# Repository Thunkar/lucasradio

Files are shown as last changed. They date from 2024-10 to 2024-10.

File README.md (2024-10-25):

# NFC based radio for kids

Uses a ESP32 A1S + PN532 NFC reader to mimic and old-school walkman

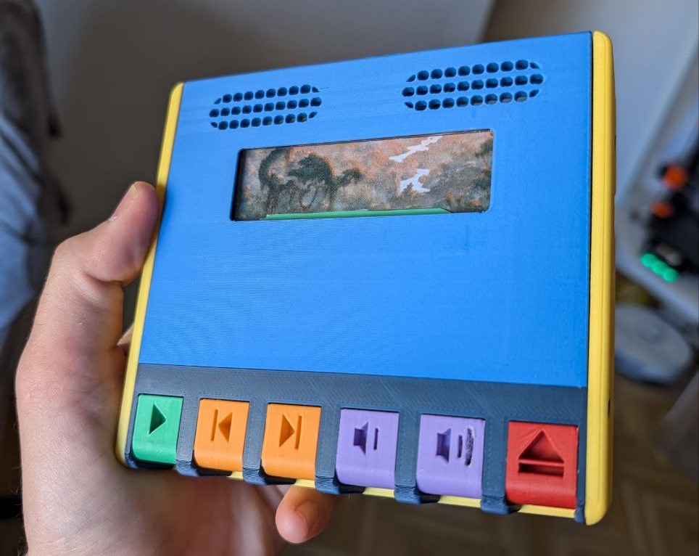
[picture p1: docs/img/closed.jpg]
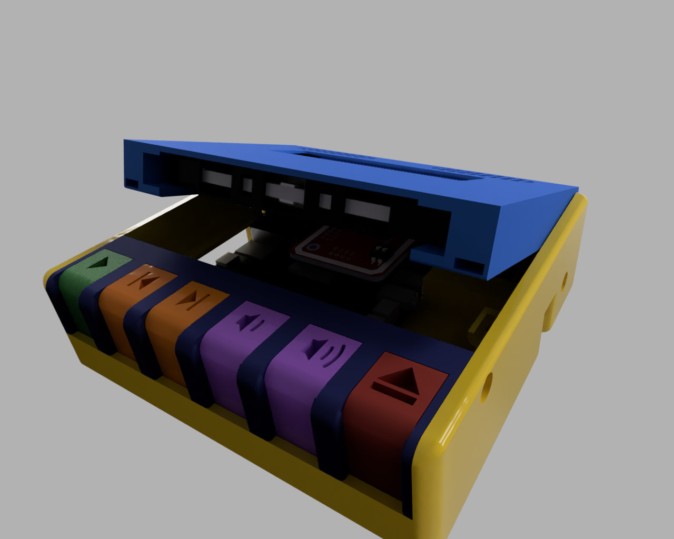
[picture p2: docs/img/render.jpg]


# Printing

PLA is fine, tolerances should allow for some wiggle room if your printer is not totally dialed in. Tested at 0.2mm layer height. Don't forget to follow on [printables](https://www.printables.com/model/1038471-nfc-walkman)!

# Ordering parts

You can check out the BOM [here](./docs/BOM.md)

# Assembly

Check out the guide [here](./docs/assembly.md)

# Flashing the code

The ESP32 A1S should be flashed with the `radio.ino` file. 

1. You will have to download and install the libraries at the top of the code, using the provided github links.
2. Use the ESP32 Dev Module board type
3. In compilation options, make sure to select "Huge app" partition scheme:

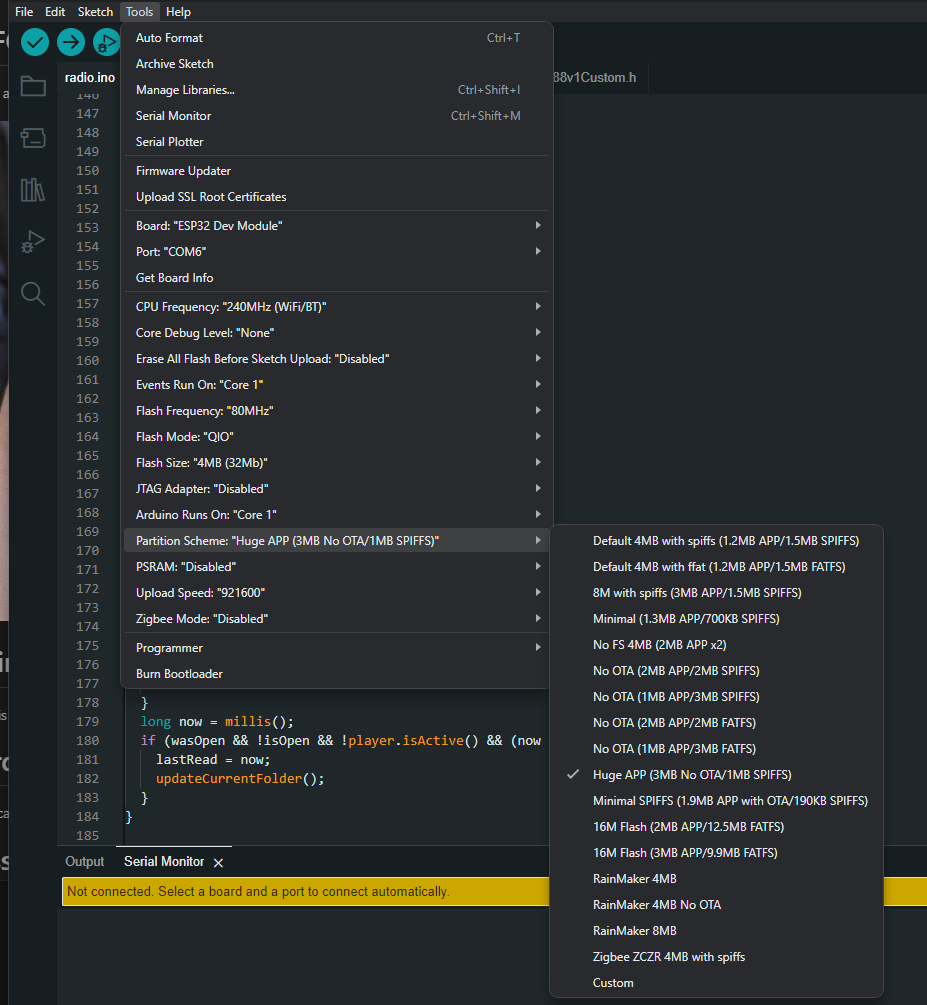
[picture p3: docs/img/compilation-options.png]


4. Click on upload!

# Operation

1. Get a microSD card and create a folder for each "cassette tape". Put some .mp3 files in each folder. Try to limit to ASCII characters!
2. Print some cassetes, and write an NFC tag for each, following the convention `P->foldername`. For example, if I have a folder in the SD card for "myalbum", the NFC tag should be written with a text record containing `P->myalbum`. (I used [Android NFC tools](https://play.google.com/store/apps/details?id=com.wakdev.wdnfc&hl=en) for this).
3. That's it! Turn on your walkman, insert your tape, and press play!

# Acknowledgements

* [Cassette model](https://www.printables.com/model/505572-cassette-tape) remixed from [Pete Farell](https://www.printables.com/@PeterFarell)'s design.

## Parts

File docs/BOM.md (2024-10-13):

# BOM

Links just provide a reference, other equivalents part might work (but the provided code expects these ones)
| Part | Link |
| ---- | ---- |
|ESP32 A1S ES8388 v2.2 | https://es.aliexpress.com/item/4000130915903.html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
|3W 4ohm speakers (x2) | https://es.aliexpress.com/item/1005006144805292.html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
|PN532 | https://es.aliexpress.com/item/1005007154965417.html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
|A3144 hall effect sensor | https://es.aliexpress.com/item/1005007816283535.html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
|M3 screws (6mm, 8mm, best to order the mix) | https://es.aliexpress.com/item/32794842281.html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
|M3 brass inserts (M3-OD 4.5, 3mm) | https://es.aliexpress.com/item/1005003582355741.html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
|4x2 magnet | https://es.aliexpress.com/item/1005003639279792.html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
|6x3 magnet | https://es.aliexpress.com/item/1005006291065081.html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
|20mm L x 5mm OD spring (x10) | https://es.aliexpress.com/item/1005005312536098.html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
|12mm latching Switch | https://es.aliexpress.com/item/1005004474876388.html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
|Battery (40mmx30mmx8mm max!) | https://es.aliexpress.com/item/1005006888230329.html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
|NFC tags | https://es.aliexpress.com/item/1005005872961523.html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

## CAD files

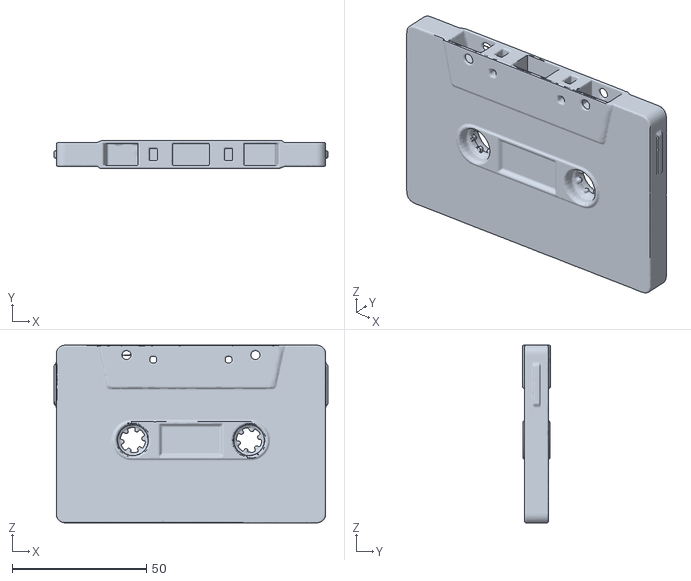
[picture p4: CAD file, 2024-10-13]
hw/cassette.stl
102.0 x 10.5 x 66.2

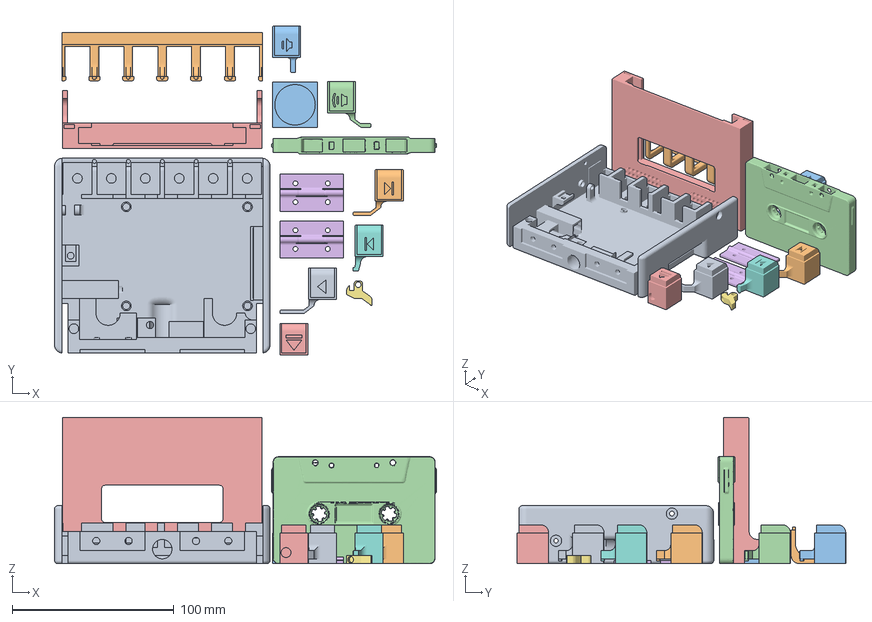
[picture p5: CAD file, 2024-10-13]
hw/recommended-orientation.3mf
236.4 x 203.4 x 90.5 mm
base.stl
buttonCover.stl
casette-tray.stl
cassette.stl
eject.stl
hinge.stl x 2
lock.stl
next.stl
play.stl
previous.stl
volumeDown.stl
volumeUp.stl
lid.stl

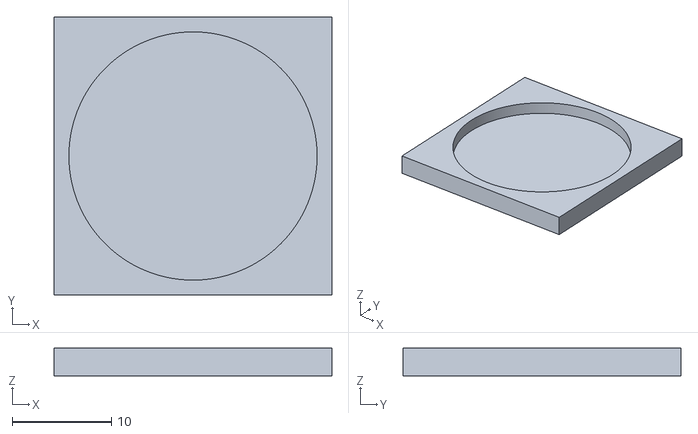
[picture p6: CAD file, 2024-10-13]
hw/casette-tray.stl
28.0 x 28.0 x 2.80

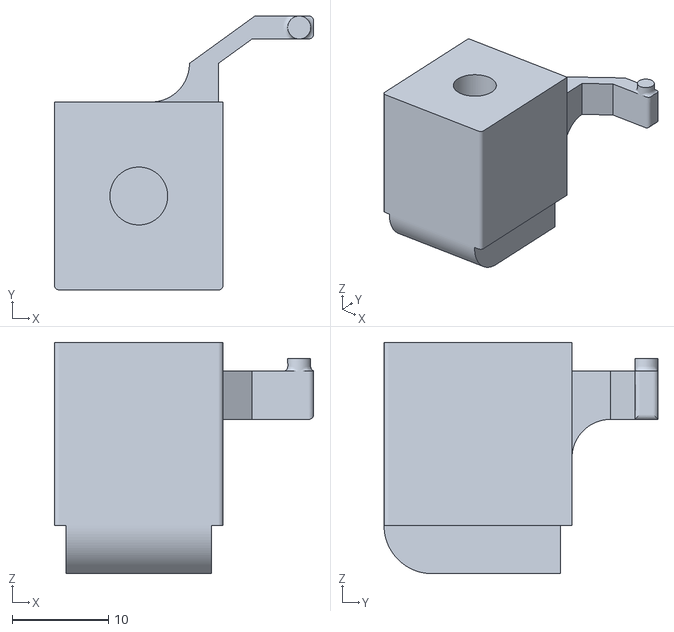
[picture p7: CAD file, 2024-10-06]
hw/volumeUp.stl
26.9 x 28.4 x 24.0

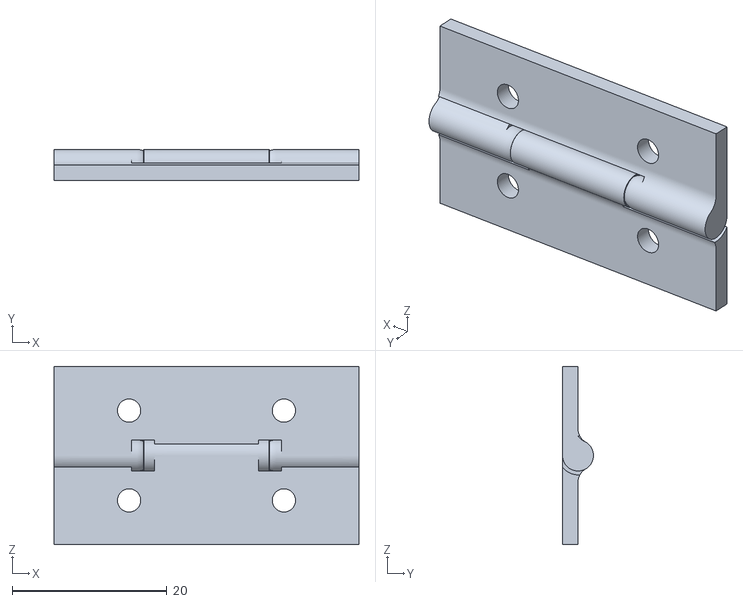
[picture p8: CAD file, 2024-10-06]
hw/hinge.stl
39.4 x 4.00 x 23.0

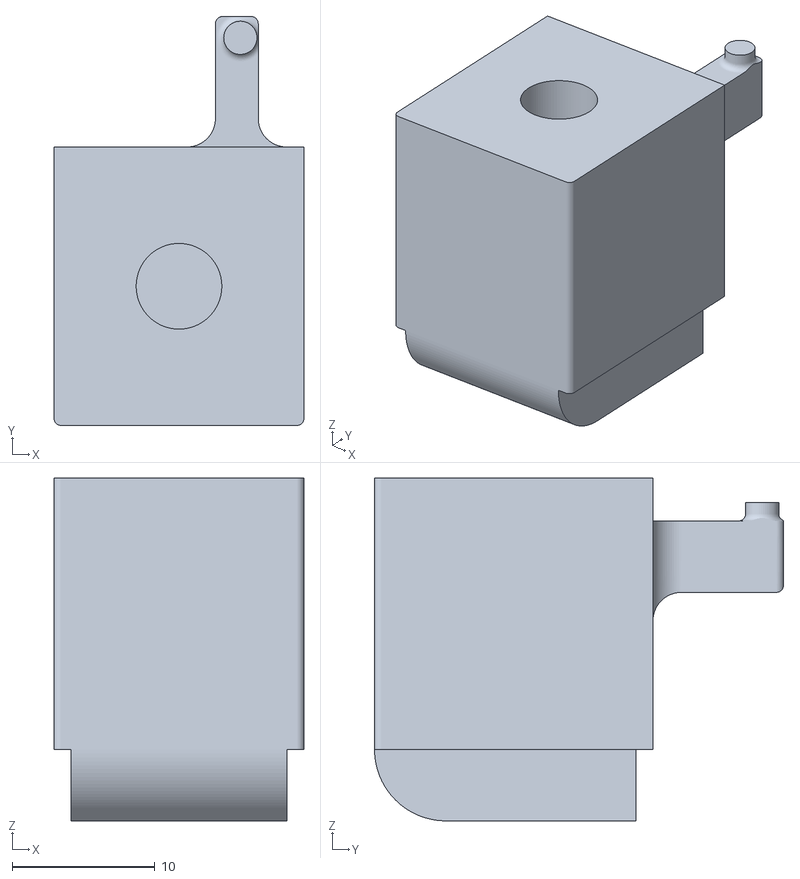
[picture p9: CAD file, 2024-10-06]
hw/volumeDown.stl
17.5 x 28.6 x 24.0

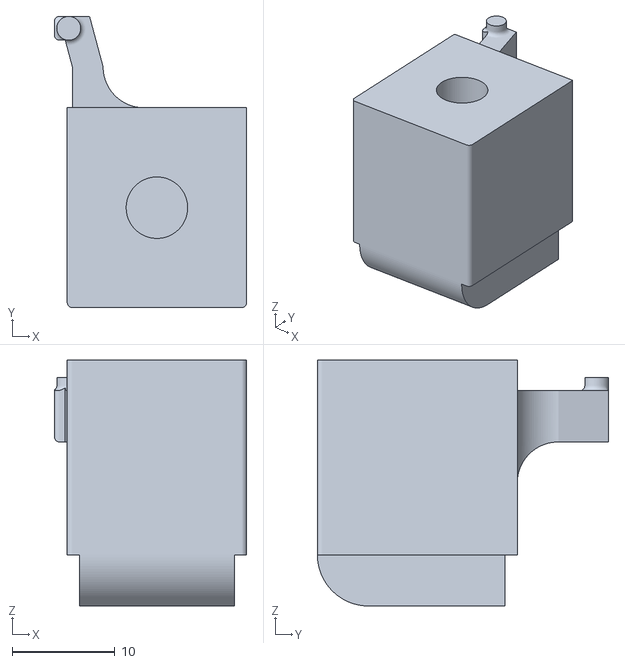
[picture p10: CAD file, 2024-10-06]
hw/next.stl
18.8 x 28.4 x 24.0

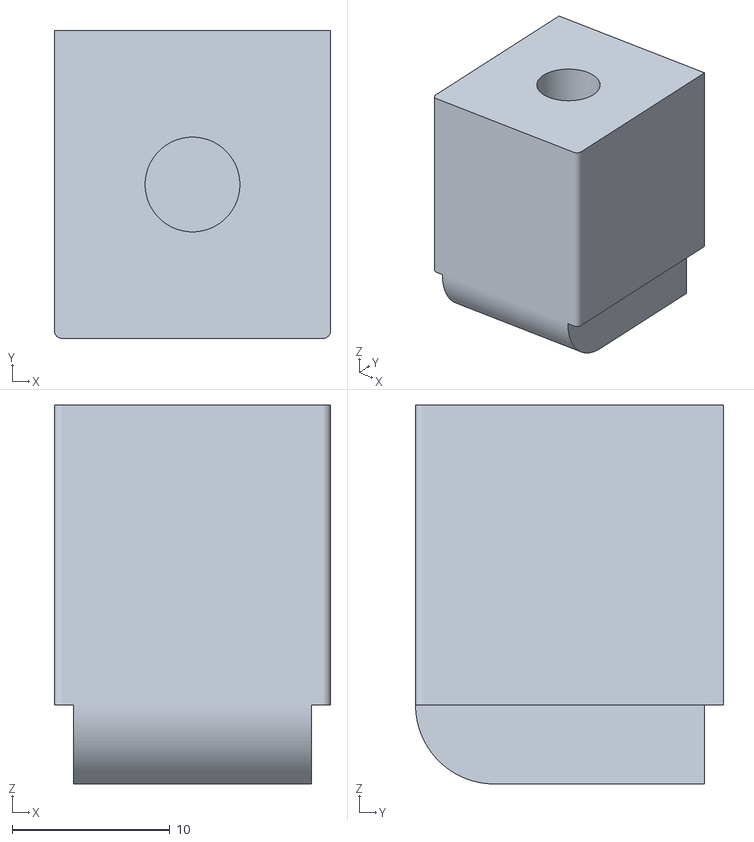
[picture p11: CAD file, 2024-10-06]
hw/eject.stl
17.5 x 19.5 x 24.0

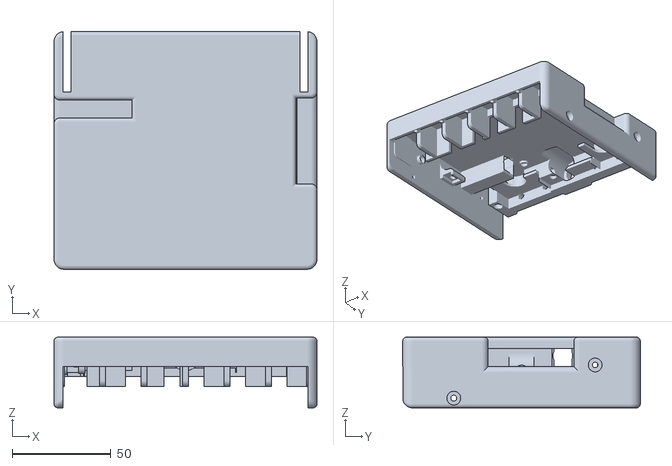
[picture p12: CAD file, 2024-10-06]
hw/base.stl
133.4 x 120.5 x 35.9

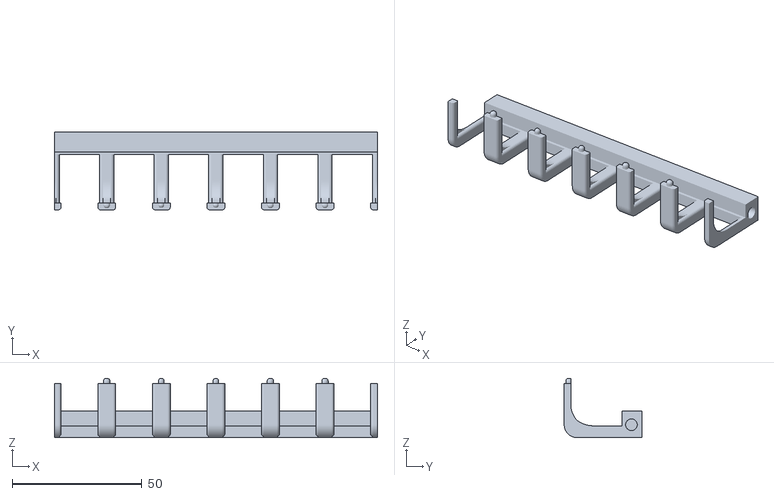
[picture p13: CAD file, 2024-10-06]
hw/buttonCover.stl
124.3 x 29.9 x 22.8

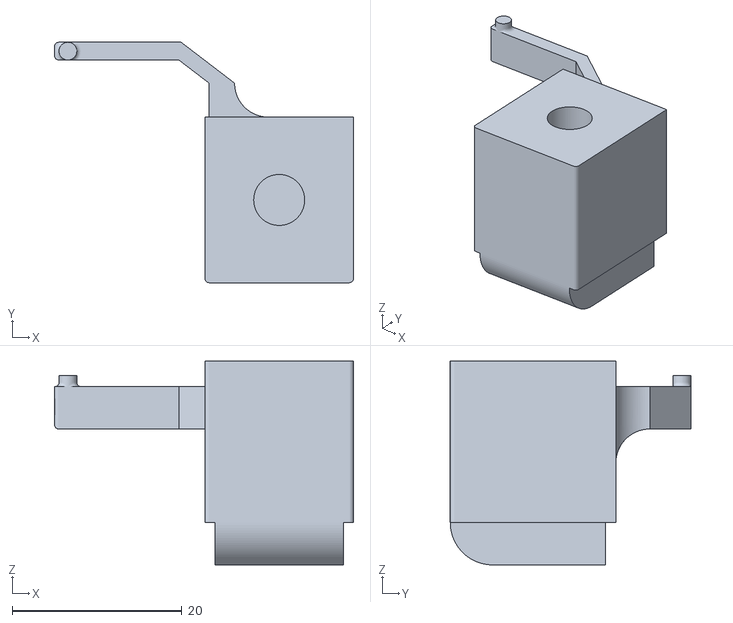
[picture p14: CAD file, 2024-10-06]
hw/play.stl
35.2 x 28.3 x 24.0

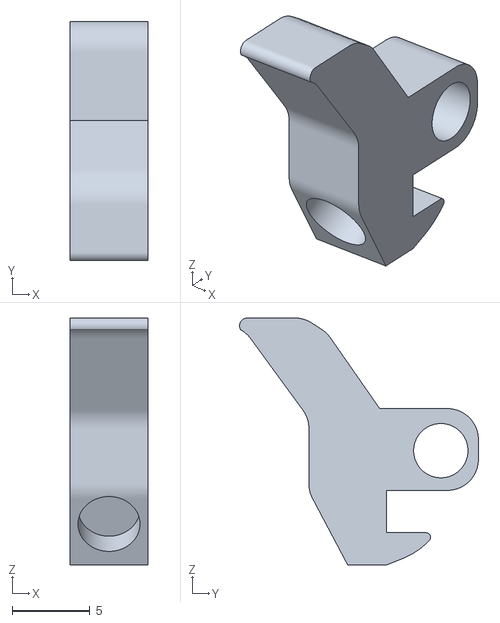
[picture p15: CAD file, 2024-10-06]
hw/lock.stl
5.00 x 15.4 x 15.9

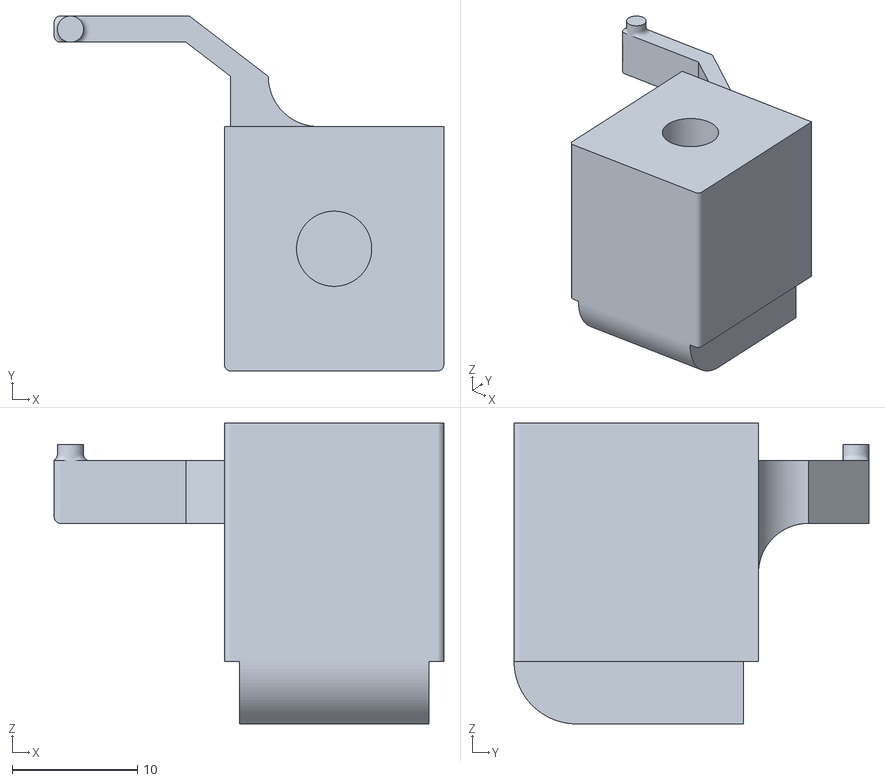
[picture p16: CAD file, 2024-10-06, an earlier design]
hw/previous.stl
31.1 x 28.3 x 24.0

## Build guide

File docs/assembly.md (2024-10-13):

# Wiring

## Preparation

Space is at a premium, so it is recommended to either desolder or cut all pins and connectors from the ESP32 A1S board. Every connection is going to be soldered on!

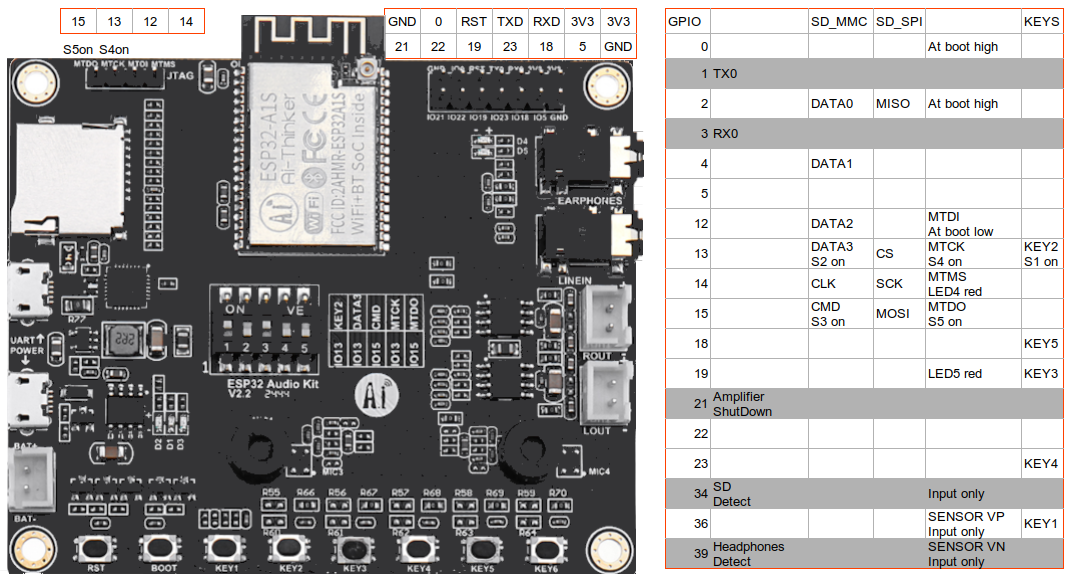
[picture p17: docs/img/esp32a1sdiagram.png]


Switches should be in the following configuration: **ON | ON | ON | OFF | OFF**

## Battery

The battery cables should be long enough to run underneath the ESP32 when mounted to the base. The switch should interrupt one of them:

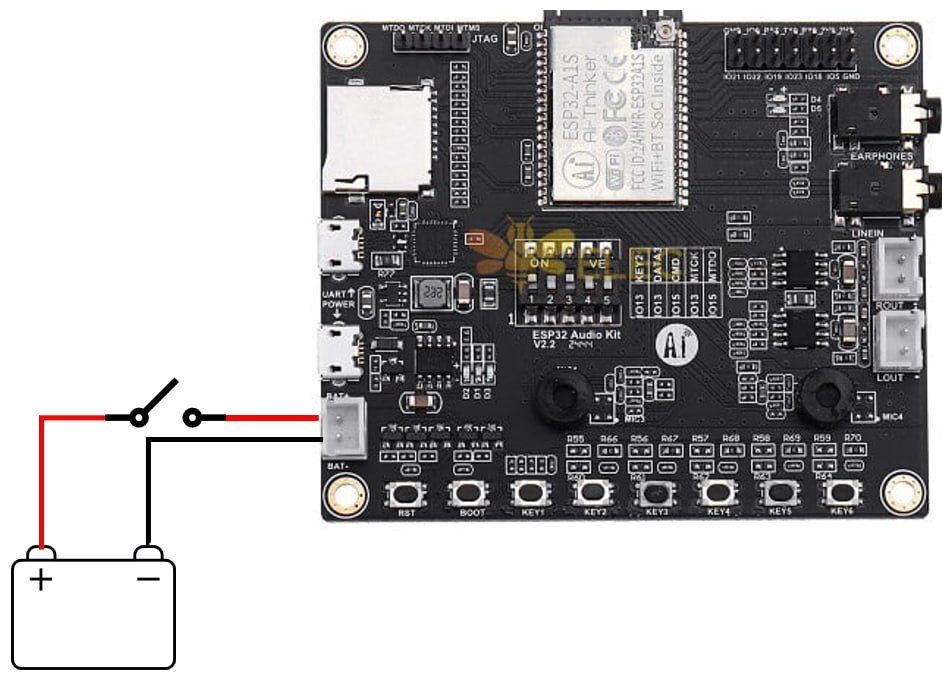
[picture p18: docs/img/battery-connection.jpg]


## Hall effect sensor

The hall effect sensor *MUST* be mounted with the beveled side facing **UP**. Only one magnet orientation is going to trigger it, so it is recommended to test this before finalizing the assembly.

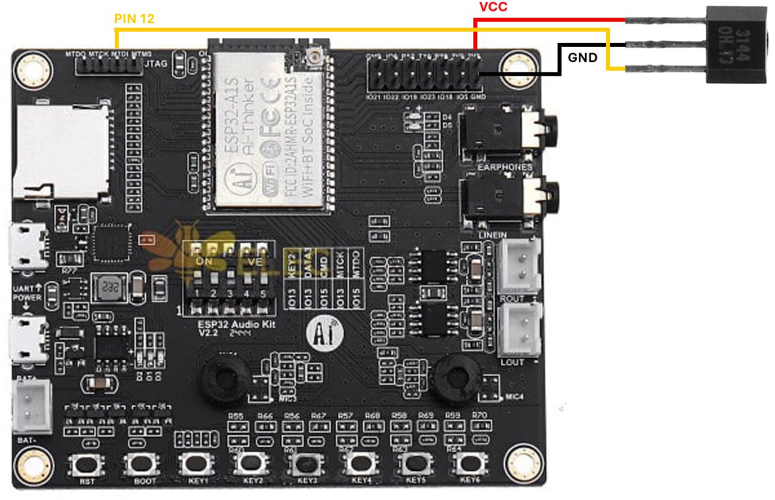
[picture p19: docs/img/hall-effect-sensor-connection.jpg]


## NFC
Make sure the PN532 is in I2C mode!

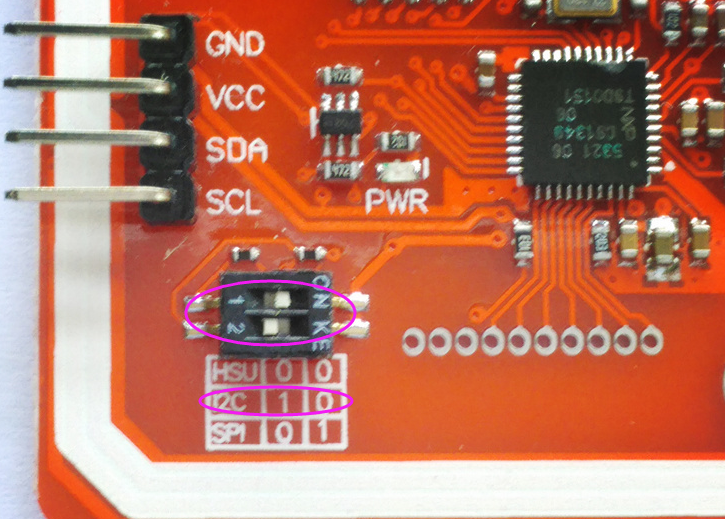
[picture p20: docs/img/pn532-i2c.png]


After that, connect it as follows:

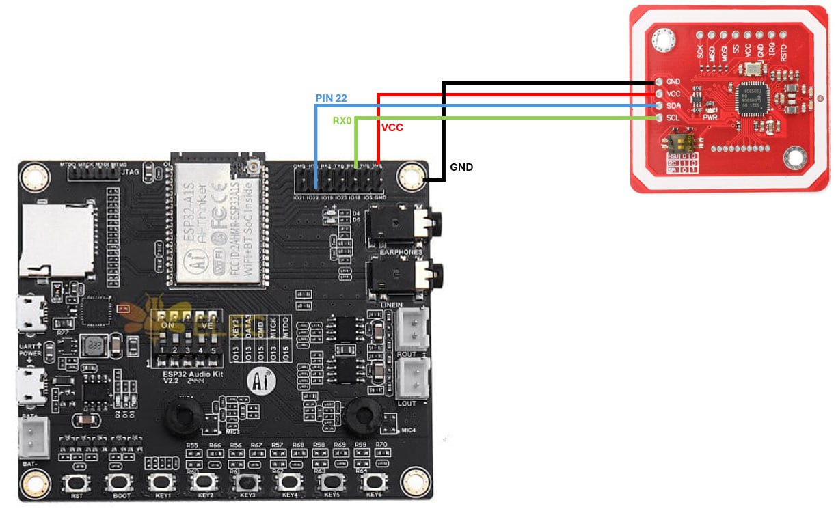
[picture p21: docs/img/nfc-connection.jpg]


## Speakers

Solder the speakers as follows:

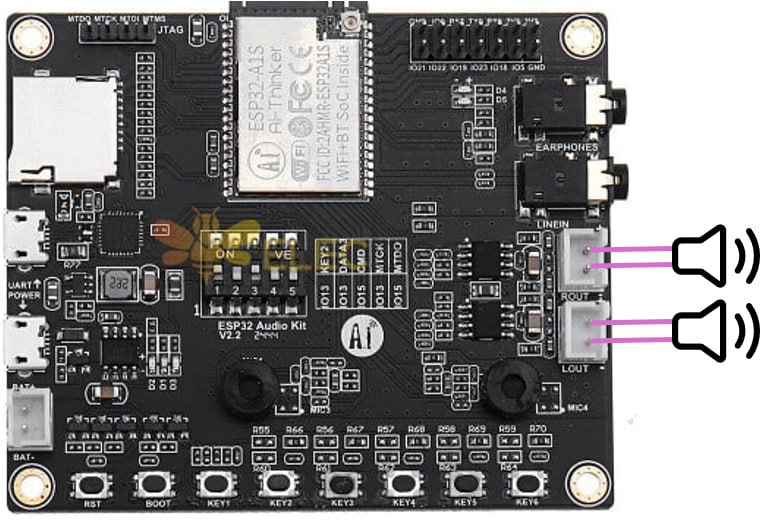
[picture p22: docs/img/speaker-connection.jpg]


## Putting it all together

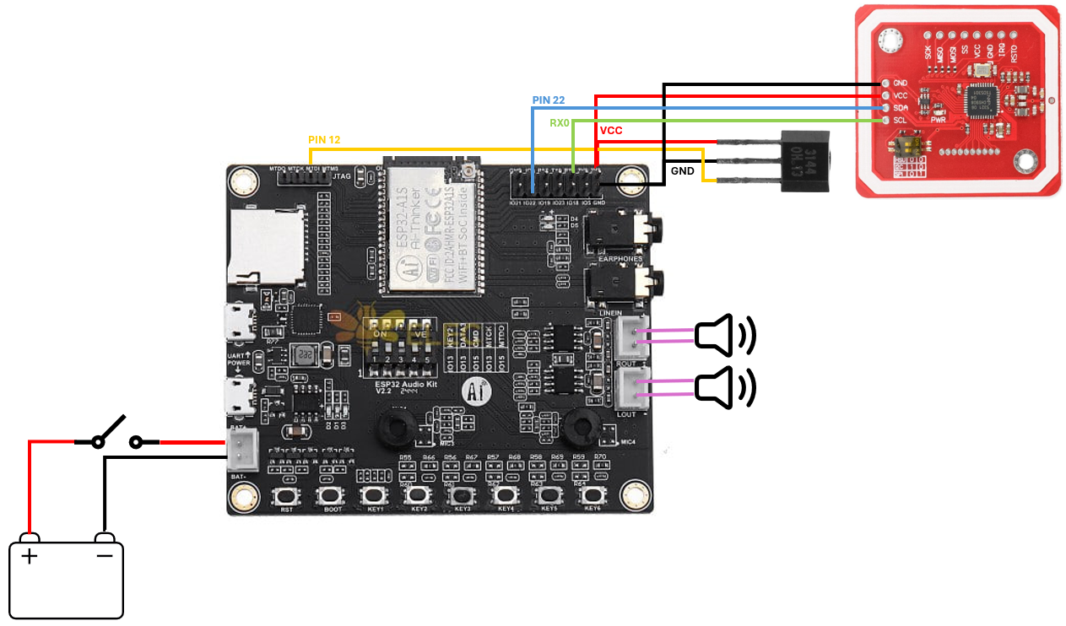
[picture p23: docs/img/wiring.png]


# Assembly

Check out the diagram below to understand how it all fits together. It is recommended to do the wiring first! <br/>
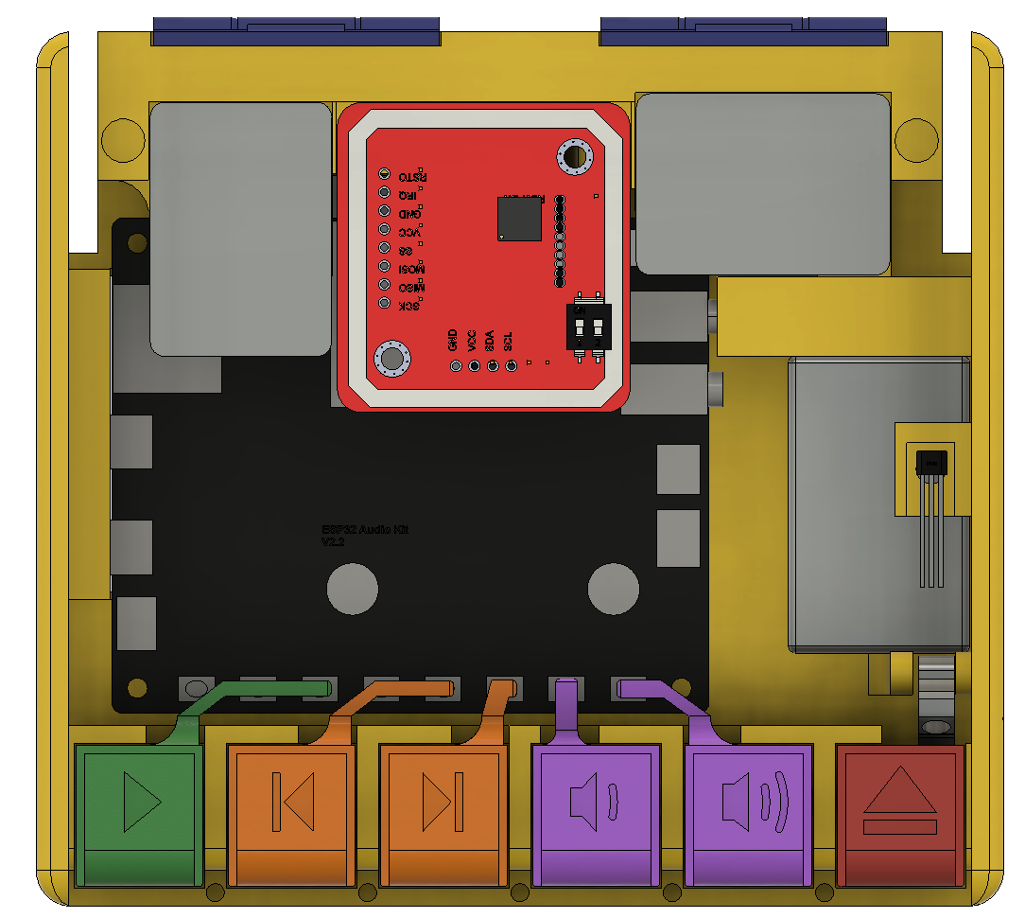
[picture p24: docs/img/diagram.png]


Every button has a spring underneath it, and the lid requires another one so that it opens automatically.

The ejection mechanism requires the magnet in the button and the lock to be oriented so they repel each other. *DO NOT TIGHTEN* the screw that holds the lock or it won't work! Worst case scenario, the holder can break and a new base would have to be printed.

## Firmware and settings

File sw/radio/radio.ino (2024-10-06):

#include "AudioTools.h" // https://github.com/pschatzmann/arduino-audio-tools
#include "AudioLibs/AudioBoardStream.h" // https://github.com/pschatzmann/arduino-audio-driver
#include "AudioLibs/AudioSourceSDFAT.h"
#include "AudioCodecs/CodecMP3Helix.h" // https://github.com/pschatzmann/arduino-libhelix
#include "Arduino.h"
#include "esp_task_wdt.h"
#include <PN532_I2C_CUSTOM.h>
#include <PN532.h> // https://github.com/elechouse/PN532
#include <NfcAdapter.h> // https://github.com/don/NDEF
#include "AudioKitEs8388v1Custom.h"

// We are not using aux in, so we don't care about jack detection and can reuse the pin
#define LID_PIN 12

#define DEBUG

#ifdef DEBUG
#define NDEF_USE_SERIAL 0
#endif

// Use I2C Bus 1 to avoid audio conflicts
TwoWire customI2C = TwoWire(1);
// We have to reuse UART RX pin and LED pin because we run out of IO
PN532_I2C_CUSTOM pn532i2c(customI2C, 22, 3);
NfcAdapter nfc = NfcAdapter(pn532i2c);

const char* startFilePath = "empty";
const char* ext = "mp3";
SdSpiConfig sdcfg(PIN_AUDIO_KIT_SD_CARD_CS, DEDICATED_SPI, SD_SCK_MHZ(10), &SPI);
AudioSourceSDFAT source(startFilePath, ext, sdcfg);
PinsAudioKitEs8388v1CustomClass PinsAudioKitEs8388v1Custom;
AudioBoard AudioKitEs8388v1Custom(AudioDriverES8388, PinsAudioKitEs8388v1Custom);
AudioBoardStream kit(AudioKitEs8388v1Custom);
MP3DecoderHelix decoder;
AudioPlayer player(source, kit, decoder);
String currentFolder;
volatile bool isOpen = false;
volatile long lastRead = 0;
// Limit reading NFC to once every second for performance reasons
long readInterval = 1000;
bool firstTimeSetFolder = true;

void volumeUp(bool, int, void*) {
  float nextVolume = constrain(player.volume() + 0.1, 0.0, 1.0);
  player.setVolume(nextVolume);
  #ifdef DEBUG
  Serial.print("Volume up: ");
  Serial.println(nextVolume);
  #endif
}

void volumeDown(bool, int, void*) {
  float nextVolume = constrain(player.volume() - 0.1, 0.0, 1.0);
  player.setVolume(nextVolume);
  #ifdef DEBUG
  Serial.print("Volume down: ");
  Serial.println(nextVolume);
  #endif
}

void startStop(bool, int, void*) {
  bool nextState = !player.isActive() && !isOpen;
  player.setActive(nextState);
  #ifdef DEBUG
  Serial.print("Play: ");
  Serial.println(nextState);
  #endif
}

void previous(bool, int, void*) {
  source.setPath(currentFolder.c_str());
  player.previous();
  #ifdef DEBUG
  Serial.println("Previous");
  #endif
}

void next(bool, int, void*) {
  source.setPath(currentFolder.c_str());
  player.next();
  #ifdef DEBUG
  Serial.println("Next");
  #endif
}

String readNFCTag() {
  String payloadAsString = "empty";

  if (nfc.tagPresent()) {
    NfcTag tag = nfc.read();
    NdefMessage message = tag.getNdefMessage();
    NdefRecord record = message.getRecord(0);
    int payloadLength = record.getPayloadLength();
    byte payload[payloadLength];
    record.getPayload(payload);
    payloadAsString = "";
    for (int c = 3; c < payloadLength; c++) {
      payloadAsString += (char)payload[c];
    }
  }
  return payloadAsString;
}

void updateCurrentFolder() {
    String command = readNFCTag();
    if (command.startsWith("P->")) {
      command.trim();
      String receivedFolder = command.substring(3);
      if (receivedFolder.equals(currentFolder)) {
        return;
      }
      currentFolder = receivedFolder;
      if (!firstTimeSetFolder) {
        firstTimeSetFolder = false;
        player.end();
      }
      #ifdef DEBUG
      Serial.print("Received command: ");
      Serial.println(command);
      Serial.print("Selecting folder: ");
      Serial.println(currentFolder);
      #endif
      source.setPath(currentFolder.c_str());
      player.setSilenceOnInactive(true);
      player.begin(0, false);
    }
}

void setup() {
  // Setup hall effect sensor
  pinMode(LID_PIN, INPUT_PULLUP);
  isOpen = digitalRead(LID_PIN);

  #ifdef DEBUG
  // Setup serial
  Serial.begin(9600);
  Serial.setTimeout(10);
  // Setup logging
  AudioLogger::instance().begin(Serial, AudioLogger::Warning);
  #endif

  // Setup output
  auto cfg = kit.defaultConfig(TX_MODE);
  kit.begin(cfg);

  // Setup additional buttons
  kit.addDefaultActions();
  kit.addAction(kit.getKey(1), startStop);
  kit.addAction(kit.getKey(3), previous);
  kit.addAction(kit.getKey(4), next);
  kit.addAction(kit.getKey(5), volumeDown);
  kit.addAction(kit.getKey(6), volumeUp);

  // Setup player
  player.setVolume(0.7);
  // Setup nfc
  nfc.begin();
  updateCurrentFolder();
}


void loop() {
  player.copy();
  kit.processActions();
  bool wasOpen = isOpen;
  isOpen = digitalRead(LID_PIN);
  if (isOpen != wasOpen) {
    if (isOpen) {
      player.end();
      currentFolder = "empty";
      source.setPath(currentFolder.c_str());
      player.setSilenceOnInactive(true);
      player.begin(0, false);
    }
    #ifdef DEBUG
    Serial.println(isOpen);
    #endif
  }
  long now = millis();
  if (wasOpen && !isOpen && !player.isActive() && (now - lastRead) > readInterval) {
    lastRead = now;
    updateCurrentFolder();
  }
}

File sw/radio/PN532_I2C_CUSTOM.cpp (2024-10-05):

/**
 * @modified picospuch
 */

#include "PN532_I2C_CUSTOM.h"
#include "PN532_debug.h"
#include "Arduino.h"

#define PN532_I2C_ADDRESS (0x48 >> 1)

PN532_I2C_CUSTOM::PN532_I2C_CUSTOM(TwoWire &wire, uint8_t sda, uint8_t scl)
{
    _wire = &wire;
    command = 0;
    _sda = sda;
    _scl = scl;
}

void PN532_I2C_CUSTOM::begin()
{   
    _wire->setClock(400000);
    _wire->begin(_sda, _scl);
}

void PN532_I2C_CUSTOM::wakeup()
{
    delay(500); // wait for all ready to manipulate pn532
}

int8_t PN532_I2C_CUSTOM::writeCommand(const uint8_t *header, uint8_t hlen, const uint8_t *body, uint8_t blen)
{
    command = header[0];
    _wire->beginTransmission(PN532_I2C_ADDRESS);

    write(PN532_PREAMBLE);
    write(PN532_STARTCODE1);
    write(PN532_STARTCODE2);

    uint8_t length = hlen + blen + 1; // length of data field: TFI + DATA
    write(length);
    write(~length + 1); // checksum of length

    write(PN532_HOSTTOPN532);
    uint8_t sum = PN532_HOSTTOPN532; // sum of TFI + DATA

    DMSG("write: ");

    for (uint8_t i = 0; i < hlen; i++)
    {
        if (write(header[i]))
        {
            sum += header[i];

            DMSG_HEX(header[i]);
        }
        else
        {
            DMSG("\nToo many data to send, I2C doesn't support such a big packet\n"); // I2C max packet: 32 bytes
            return PN532_INVALID_FRAME;
        }
    }

    for (uint8_t i = 0; i < blen; i++)
    {
        if (write(body[i]))
        {
            sum += body[i];

            DMSG_HEX(body[i]);
        }
        else
        {
            DMSG("\nToo many data to send, I2C doesn't support such a big packet\n"); // I2C max packet: 32 bytes
            return PN532_INVALID_FRAME;
        }
    }

    uint8_t checksum = ~sum + 1; // checksum of TFI + DATA
    write(checksum);
    write(PN532_POSTAMBLE);

    _wire->endTransmission();

    DMSG('\n');

    return readAckFrame();
}

int16_t PN532_I2C_CUSTOM::getResponseLength(uint8_t buf[], uint8_t len, uint16_t timeout)
{
    const uint8_t PN532_NACK[] = {0, 0, 0xFF, 0xFF, 0, 0};
    uint16_t time = 0;

    do
    {
        if (_wire->requestFrom(PN532_I2C_ADDRESS, 6))
        {
            if (read() & 1)
            {          // check first byte --- status
                break; // PN532 is ready
            }
        }

        delay(1);
        time++;
        if ((0 != timeout) && (time > timeout))
        {
            return -1;
        }
    } while (1);

    if (0x00 != read() || // PREAMBLE
        0x00 != read() || // STARTCODE1
        0xFF != read()    // STARTCODE2
    )
    {

        return PN532_INVALID_FRAME;
    }

    uint8_t length = read();

    // request for last respond msg again
    _wire->beginTransmission(PN532_I2C_ADDRESS);
    for (uint16_t i = 0; i < sizeof(PN532_NACK); ++i)
    {
        write(PN532_NACK[i]);
    }
    _wire->endTransmission();

    return length;
}

int16_t PN532_I2C_CUSTOM::readResponse(uint8_t buf[], uint8_t len, uint16_t timeout)
{
    uint16_t time = 0;
    uint8_t length;

    length = getResponseLength(buf, len, timeout);

    // [RDY] 00 00 FF LEN LCS (TFI PD0 ... PDn) DCS 00
    do
    {
        if (_wire->requestFrom(PN532_I2C_ADDRESS, 6 + length + 2))
        {
            if (read() & 1)
            {          // check first byte --- status
                break; // PN532 is ready
            }
        }

        delay(1);
        time++;
        if ((0 != timeout) && (time > timeout))
        {
            return -1;
        }
    } while (1);

    if (0x00 != read() || // PREAMBLE
        0x00 != read() || // STARTCODE1
        0xFF != read()    // STARTCODE2
    )
    {

        return PN532_INVALID_FRAME;
    }

    length = read();

    if (0 != (uint8_t)(length + read()))
    { // checksum of length
        return PN532_INVALID_FRAME;
    }

    uint8_t cmd = command + 1; // response command
    if (PN532_PN532TOHOST != read() || (cmd) != read())
    {
        return PN532_INVALID_FRAME;
    }

    length -= 2;
    if (length > len)
    {
        return PN532_NO_SPACE; // not enough space
    }

    DMSG("read:  ");
    DMSG_HEX(cmd);

    uint8_t sum = PN532_PN532TOHOST + cmd;
    for (uint8_t i = 0; i < length; i++)
    {
        buf[i] = read();
        sum += buf[i];

        DMSG_HEX(buf[i]);
    }
    DMSG('\n');

    uint8_t checksum = read();
    if (0 != (uint8_t)(sum + checksum))
    {
        DMSG("checksum is not ok\n");
        return PN532_INVALID_FRAME;
    }
    read(); // POSTAMBLE

    return length;
}

int8_t PN532_I2C_CUSTOM::readAckFrame()
{
    const uint8_t PN532_ACK[] = {0, 0, 0xFF, 0, 0xFF, 0};
    uint8_t ackBuf[sizeof(PN532_ACK)];

    DMSG("wait for ack at : ");
    DMSG(millis());
    DMSG('\n');

    uint16_t time = 0;
    do
    {
        if (_wire->requestFrom(PN532_I2C_ADDRESS, sizeof(PN532_ACK) + 1))
        {
            if (read() & 1)
            {          // check first byte --- status
                break; // PN532 is ready
            }
        }

        delay(1);
        time++;
        if (time > PN532_ACK_WAIT_TIME)
        {
            DMSG("Time out when waiting for ACK\n");
            return PN532_TIMEOUT;
        }
    } while (1);

    DMSG("ready at : ");
    DMSG(millis());
    DMSG('\n');

    for (uint8_t i = 0; i < sizeof(PN532_ACK); i++)
    {
        ackBuf[i] = read();
    }

    if (memcmp(ackBuf, PN532_ACK, sizeof(PN532_ACK)))
    {
        DMSG("Invalid ACK\n");
        return PN532_INVALID_ACK;
    }

    return 0;
}

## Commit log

2024-10-06 added stls
    [base.stl, buttonCover.stl, eject.stl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]
2024-10-13 Add files via upload
    Add tray stl
    [casette-tray.stl]
2024-10-13 more docs and fixes
    [cassette.stl, recommended-orientation.3mf]
